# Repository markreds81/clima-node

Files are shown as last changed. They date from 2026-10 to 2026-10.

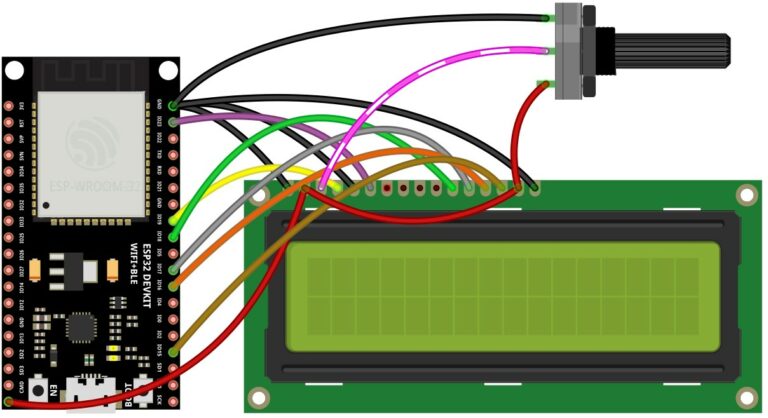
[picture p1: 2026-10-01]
docs/images/lcd-esp32-wiring.jpg

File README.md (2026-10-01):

# ClimaNode

Nodo climatico basato su ESP32-WROOM-32: legge temperatura e umidità da un sensore DHT22, le mostra su un display LCD 16x2 ed espone gli ultimi valori rilevati tramite una semplice API HTTP in JSON e una dashboard web.

## Hardware

- Scheda ESP32-WROOM-32
- Sensore DHT22
- Display LCD 16x2 (interfaccia parallela, driver HD44780 compatibile con `LiquidCrystal`)
- Encoder rotativo con pulsante integrato (es. KY-040)

### Collegamenti

| Componente | Pin ESP32 |
|---|---|
| DHT22 (data) | GPIO 21 |
| LCD RS | GPIO 19 |
| LCD E | GPIO 23 |
| LCD D4 | GPIO 18 |
| LCD D5 | GPIO 17 |
| LCD D6 | GPIO 16 |
| LCD D7 | GPIO 15 |
| Encoder CLK | GPIO 4 |
| Encoder DT | GPIO 22 |
| Encoder SW (push) | GPIO 27 |

## Librerie richieste

Da installare tramite Library Manager dell'Arduino IDE:

- **DHT sensor library** (Adafruit) — con la sua dipendenza **Adafruit Unified Sensor**
- **LiquidCrystal** (libreria standard, inclusa con l'Arduino IDE)
- **RotaryEncoder** (Matthias Hertel)
- **ESP Async WebServer** (ESP32Async) — con la sua dipendenza **Async TCP** (ESP32Async)

Incluse direttamente nel progetto (nessuna installazione necessaria):

- `Button` ([mrButton](https://github.com/markreds81/Button) di Mark Reds, vendorizzata come `Button.h`/`Button.cpp`)

Già incluse nel core ESP32 (nessuna installazione necessaria, basta avere il core ESP32 installato tramite Boards Manager):

- `WiFi`
- `ESPmDNS`

## Setup credenziali WiFi

Le credenziali WiFi non sono versionate nel repository. Prima di compilare:

1. Copia il file di esempio:
   ```sh
   cp Secrets.h.example Secrets.h
   ```
2. Modifica `Secrets.h` inserendo SSID e password delle reti WiFi disponibili (sono supportate fino a due reti, il nodo si connette a quella con il segnale migliore e, se la connessione cade, riprova automaticamente senza bloccare display e sensore):
   ```cpp
   #define WIFI_SSID_1  "NomeRete1"
   #define WIFI_PASS_1  "Password1"

   #define WIFI_SSID_2  "NomeRete2"
   #define WIFI_PASS_2  "Password2"
   ```

`Secrets.h` è ignorato da git (vedi `.gitignore`) e non verrà mai inviato al repository remoto.

## Upload

Apri `ClimaNode.ino` con l'Arduino IDE, seleziona la board ESP32-WROOM-32 e la porta seriale corretta, quindi carica lo sketch.

Al boot il device si connette al WiFi (log disponibile su Serial a 9600 baud) e, una volta connesso, avvia anche il responder mDNS, raggiungibile come `climanode-XXXXXX.local` sulla rete locale.

## Identificazione del nodo

Ogni nodo è identificato dal MAC address di fabbrica dell'ESP32 (scritto nell'eFuse, unico per chip e indipendente dal firmware):

- **ID**: il MAC in esadecimale minuscolo, es. `a1b2c3d4e5f6`. È incluso in tutte le risposte dell'API (campo `id`) e nel record TXT `id` del servizio mDNS `_http._tcp`.
- **Hostname**: `climanode-` seguito dagli ultimi 3 byte del MAC, es. `climanode-d4e5f6`. È usato sia per mDNS (`climanode-d4e5f6.local`) sia come nome DHCP, così più nodi possono convivere sulla stessa rete.

ID e hostname sono stampati su Serial all'avvio. Per elencare i nodi presenti sulla rete da macOS:

```sh
dns-sd -B _http._tcp
```

## Display LCD

Il display mostra sei schermate, che si scorrono ruotando l'encoder in entrambe le direzioni:

- **Clima**: temperatura e umidità rilevate dal DHT22, indicate da due icone (termometro e goccia). In fondo a ogni riga una freccia indica la tendenza: ↑ in salita, ↓ in discesa, → stabile, calcolata confrontando la media dell'ultimo minuto con quella di 10 minuti prima (soglie: 0,3 °C e 2% di umidità). Nei primi minuti dopo l'avvio, finché lo storico non è sufficiente, la freccia non viene mostrata.
- **Rete**: indirizzo IP e stato della connessione WiFi.
- **Segnale**: qualità del segnale WiFi (ottimo, buono, discreto, scarso), una barra proporzionale e il valore RSSI in dBm, aggiornati ogni secondo.
- **Data e ora**: data e ora correnti, sincronizzate via NTP (fuso Europe/Rome con ora legale automatica).
- **Nodo**: ID del nodo (MAC di fabbrica) e hostname.
- **Firmware**: versione del firmware installato.

Il pulsante integrato nell'encoder è collegato (GPIO 27) ma al momento non ha alcuna funzione.

## Dashboard web

Una volta connesso alla rete, aprendo `http://climanode-XXXXXX.local/` (o l'IP stampato su Serial) nel browser è disponibile una dashboard single-page che mostra ID del nodo, versione del firmware, data e ora del device, temperatura e umidità con la relativa tendenza, e stato della connessione WiFi (SSID, potenza del segnale, IP, canale), aggiornata automaticamente ogni 3 secondi.

## API

Il device espone anche due endpoint HTTP in JSON, usati dalla dashboard ma interrogabili anche direttamente:

```
GET /api/v1/climate
```

```json
{"id":"a1b2c3d4e5f6","temperature":21.5,"humidity":48.2,"trend":{"temperature":"up","humidity":"steady"}}
```

`trend` indica la tendenza di ciascun valore negli ultimi 10 minuti (come le frecce sul display): `up`, `down`, `steady`, oppure `unknown` nei primi minuti dopo l'avvio.

```
GET /api/v1/status
```

```json
{"id":"a1b2c3d4e5f6","firmware":"1.0a","wifi":{"connected":true,"ssid":"NomeRete","rssi":-58,"ip":"192.168.1.50","channel":6},"time":{"synced":true,"local":"2026-10-01T14:05:32"}}
```

Se il device non è connesso al WiFi, `wifi.connected` risulta `false` e gli altri campi sono assenti. `time.local` è l'ora locale del device in formato ISO 8601 senza offset; finché l'ora non è sincronizzata via NTP `time.synced` risulta `false` e `local` è assente.

Esempio con `curl`, usando l'IP stampato su Serial oppure l'hostname mDNS:

```sh
curl http://climanode-d4e5f6.local/api/v1/climate
curl http://climanode-d4e5f6.local/api/v1/status
```

## Licenza

Distribuito sotto licenza [MIT](LICENSE).

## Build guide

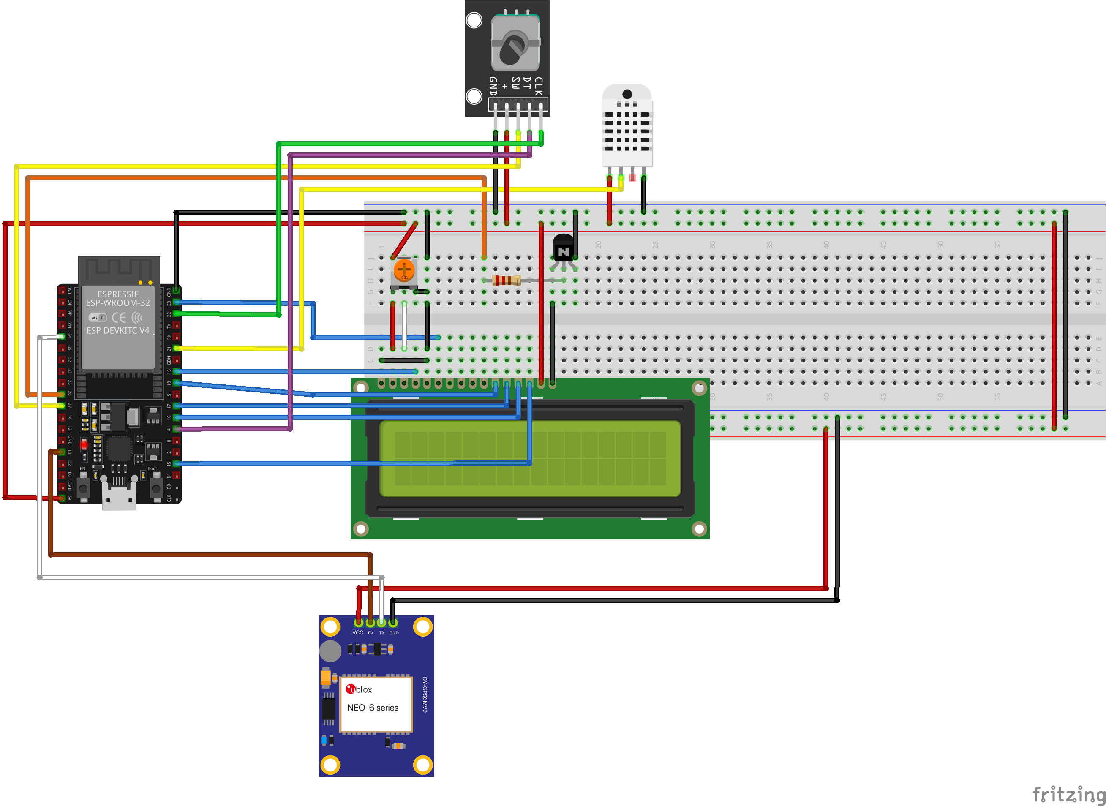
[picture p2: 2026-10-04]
docs/images/climanode-wiring.png

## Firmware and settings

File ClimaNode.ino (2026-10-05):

#include <DHT.h>
#include <LiquidCrystal.h>
#include <WiFi.h>
#include <ESPAsyncWebServer.h>
#include <ESPmDNS.h>
#include <esp_mac.h>
#include <RotaryEncoder.h>
#include <TinyGPSPlus.h>
#include <sys/time.h>
#include "time.h"
#include "Timer.h"
#include "Secrets.h"
#include "Dashboard.h"
#include "Button.h"
#include "Trend.h"
#include "Glyphs.h"

#define LCD_RS            19
#define LCD_EN            23
#define LCD_D4            18
#define LCD_D5            17
#define LCD_D6            16
#define LCD_D7            15
#define LCD_BACKLIGHT     26
#define DHT_PIN           21
#define DHT_TYPE          DHT22
#define HTTP_PORT         80
#define HOSTNAME_PREFIX   "climanode"
#define FIRMWARE_VERSION  "1.0a"
#define ROTARY_CLK        4
#define ROTARY_DT         22
#define ROTARY_SW         27
#define BACKLIGHT_TIMEOUT 30000L
#define GPS_RX            34
#define GPS_TX            13
#define GPS_BAUD          9600
#define GPS_MAX_AGE       3000

#define NTP_SERVER        "ntp1.inrim.it"
// Europe/Rome: CET (UTC+1), CEST (UTC+2) dall'ultima domenica di marzo all'ultima di ottobre
#define TIME_ZONE         "CET-1CEST,M3.5.0,M10.5.0/3"

DHT dht(DHT_PIN, DHT_TYPE);
LiquidCrystal lcd(LCD_RS, LCD_EN, LCD_D4, LCD_D5, LCD_D6, LCD_D7);
RotaryEncoder rot(ROTARY_CLK, ROTARY_DT, RotaryEncoder::LatchMode::FOUR3);
Button btn(ROTARY_SW);
AsyncWebServer httpServer(HTTP_PORT);
Timer linkTimer;
Timer pollTimer;
Timer clockTimer;
Timer trendTimer;
Timer backlightTimer;
Timer gpsTimer;
TinyGPSPlus gps;
Trend temperatureTrend(0.3f);  // °C in TREND_WINDOW_MIN minuti
Trend humidityTrend(2.0f);     // % in TREND_WINDOW_MIN minuti
volatile TrendDirection temperatureDirection = TREND_UNKNOWN;
volatile TrendDirection humidityDirection = TREND_UNKNOWN;

enum DisplayScreen {
  SCREEN_CLIMATE,
  SCREEN_NETWORK,
  SCREEN_SIGNAL,
  SCREEN_TIME,
  SCREEN_GPS,
  SCREEN_NODE,
  SCREEN_FIRMWARE,
  SCREEN_COUNT
};

struct GpsInfo {
  bool fix;
  uint32_t satellites;
  double latitude;
  double longitude;
  double altitude;  // m s.l.m.
  double hdop;
};

GpsInfo gpsInfo = {};
portMUX_TYPE gpsMux = portMUX_INITIALIZER_UNLOCKED;

struct KnownNetwork {
  const char *ssid;
  const char *pass;
};

const KnownNetwork knownNetworks[] = {
  { WIFI_SSID_1, WIFI_PASS_1 },
  { WIFI_SSID_2, WIFI_PASS_2 }
};

enum LinkState {
  LINK_IDLE,        // in attesa del prossimo tentativo
  LINK_SCANNING,    // scansione asincrona in corso
  LINK_CONNECTING,  // WiFi.begin() avviato, in attesa dell'esito
  LINK_CONNECTED
};

const uint32_t connectTimeoutMs = 10000;
const uint32_t scanTimeoutMs = 15000;
const uint32_t retryDelayMs = 5000;
LinkState linkState = LINK_IDLE;
uint32_t linkStateSince = 0;
uint8_t wifiStatus = WL_NO_SHIELD;
bool mdnsStarted = false;
char nodeId[13];    // MAC di fabbrica (eFuse) in esadecimale, es. "a1b2c3d4e5f6"
char hostname[24];  // HOSTNAME_PREFIX + ultimi 3 byte del MAC, es. "climanode-d4e5f6"
float humidity = 0.0f;
float temperature = 0.0f;
DisplayScreen currentScreen = SCREEN_CLIMATE;
bool backlightOn = true;

uint8_t trendSymbol(TrendDirection trend) {
  switch (trend) {
    case TREND_UP:
      return ICON_TREND_UP;
    case TREND_DOWN:
      return ICON_TREND_DOWN;
    case TREND_STEADY:
      return LCD_RIGHT_ARROW;
    default:
      return ' ';
  }
}

void printClimateLine(uint8_t row, uint8_t icon, const char *value, TrendDirection trend) {
  lcd.setCursor(0, row);
  lcd.print(' ');
  lcd.write(icon);
  lcd.printf(" %-11s", value);
  lcd.write(trendSymbol(trend));
  lcd.print(' ');
}

void renderClimateScreen() {
  char value[14];

  snprintf(value, sizeof(value), "%5.1f%cC", temperature, LCD_DEGREE);
  printClimateLine(0, ICON_THERMOMETER, value, temperatureTrend.direction());

  snprintf(value, sizeof(value), "%5.1f%%", humidity);
  printClimateLine(1, ICON_DROP, value, humidityTrend.direction());
}

void renderNetworkScreen() {
  lcd.setCursor(0, 0);
  if (WiFi.status() == WL_CONNECTED) {
    lcd.print(WiFi.localIP().toString());
    lcd.print("                ");
  } else {
    lcd.print("IP non disp.    ");
  }

  lcd.setCursor(0, 1);
  lcd.print(WiFi.status() == WL_CONNECTED ? "WiFi: Connesso  " : "WiFi: Assente   ");
}

const char *signalQuality(int rssi) {
  if (rssi >= -55) return "ottimo";
  if (rssi >= -65) return "buono";
  if (rssi >= -75) return "discreto";
  return "scarso";
}

void renderSignalScreen() {
  char line[17];

  if (WiFi.status() != WL_CONNECTED) {
    lcd.setCursor(0, 0);
    lcd.print("Segnale WiFi    ");
    lcd.setCursor(0, 1);
    lcd.print("Non connesso    ");
    return;
  }

  int rssi = WiFi.RSSI();
  snprintf(line, sizeof(line), "Segnale %-8s", signalQuality(rssi));
  lcd.setCursor(0, 0);
  lcd.print(line);

  // Barra di 9 celle da -90 dBm (vuota) a -30 dBm (piena), poi il valore in dBm
  const int barCells = 9;
  int filled = constrain(map(rssi, -90, -30, 0, barCells), 0, barCells);
  for (int i = 0; i < barCells; i++) {
    line[i] = i < filled ? LCD_FULL_BLOCK : LCD_MIDDLE_DOT;
  }
  snprintf(line + barCells, sizeof(line) - barCells, "%4ddBm", rssi);
  lcd.setCursor(0, 1);
  lcd.print(line);
}

void renderTimeScreen() {
  struct tm timeInfo;
  
  if (!getLocalTime(&timeInfo, 0)) {
    lcd.setCursor(0, 0);
    lcd.print("Ora non sincr.  ");
    lcd.setCursor(0, 1);
    lcd.print("Attesa NTP...   ");
    return;
  }

  char line[17];
  strftime(line, sizeof(line), "   %d/%m/%Y   ", &timeInfo);
  lcd.setCursor(0, 0);
  lcd.print(line);

  strftime(line, sizeof(line), "    %H:%M:%S    ", &timeInfo);
  lcd.setCursor(0, 1);
  lcd.print(line);
}

GpsInfo readGpsInfo() {
  taskENTER_CRITICAL(&gpsMux);
  GpsInfo info = gpsInfo;
  taskEXIT_CRITICAL(&gpsMux);
  return info;
}

void renderGpsScreen() {
  GpsInfo info = readGpsInfo();
  char line[17];

  if (!info.fix) {
    lcd.setCursor(0, 0);
    lcd.print("GPS: ricerca... ");
    snprintf(line, sizeof(line), "Satelliti: %-5lu", (unsigned long)info.satellites);
    lcd.setCursor(0, 1);
    lcd.print(line);
    return;
  }

  snprintf(line, sizeof(line), "Lat: %9.5f %c", fabs(info.latitude), info.latitude < 0 ? 'S' : 'N');
  lcd.setCursor(0, 0);
  lcd.print(line);

  snprintf(line, sizeof(line), "Lon: %9.5f %c", fabs(info.longitude), info.longitude < 0 ? 'W' : 'E');
  lcd.setCursor(0, 1);
  lcd.print(line);
}

void renderNodeScreen() {
  char line[17];
  snprintf(line, sizeof(line), "ID: %-12.12s", nodeId);
  lcd.setCursor(0, 0);
  lcd.print(line);

  snprintf(line, sizeof(line), "%-16.16s", hostname);
  lcd.setCursor(0, 1);
  lcd.print(line);
}

void renderFirmwareScreen() {
  char line[17];
  lcd.setCursor(0, 0);
  lcd.print("ClimaNode       ");

  snprintf(line, sizeof(line), "Firmware %-7s", FIRMWARE_VERSION);
  lcd.setCursor(0, 1);
  lcd.print(line);
}

void wakeBacklight() {
  backlightTimer.reset();
  if (!backlightOn) {
    backlightOn = true;
    digitalWrite(LCD_BACKLIGHT, HIGH);
  }
}

void renderDisplay() {
  switch (currentScreen) {
    case SCREEN_CLIMATE:
      renderClimateScreen();
      break;
    case SCREEN_NETWORK:
      renderNetworkScreen();
      break;
    case SCREEN_SIGNAL:
      renderSignalScreen();
      break;
    case SCREEN_TIME:
      renderTimeScreen();
      break;
    case SCREEN_GPS:
      renderGpsScreen();
      break;
    case SCREEN_NODE:
      renderNodeScreen();
      break;
    case SCREEN_FIRMWARE:
      renderFirmwareScreen();
      break;
  }
}

void readEnvironment() {
  float newHumidity = dht.readHumidity();
  float newTemperature = dht.readTemperature();

  if (isnan(newHumidity) || isnan(newTemperature)) {
    Serial.println("Errore: lettura sensore non valida");
    if (currentScreen == SCREEN_CLIMATE) {
      lcd.setCursor(0, 0);
      lcd.print("Errore sensore  ");
      lcd.setCursor(0, 1);
      lcd.print("Dati non validi ");
    }
    return;
  }

  humidity = newHumidity;
  temperature = newTemperature;
  humidityTrend.add(humidity);
  temperatureTrend.add(temperature);

#ifdef DHT_DEBUG
  Serial.print("Umidità: ");
  Serial.print(humidity, 1);
  Serial.print("%, Temperatura: ");
  Serial.print(temperature, 1);
  Serial.println("° Celsius");
#endif

  if (currentScreen == SCREEN_CLIMATE) {
    renderClimateScreen();
  }
}

// Copia src in dst come contenuto di una stringa JSON (senza virgolette esterne)
void jsonEscape(const char *src, char *dst, size_t size) {
  size_t n = 0;
  for (; *src && n + 7 <= size; src++) {
    unsigned char c = *src;
    if (c == '"' || c == '\\') {
      dst[n++] = '\\';
      dst[n++] = c;
    } else if (c < 0x20) {
      n += snprintf(dst + n, size - n, "\\u%04x", c);
    } else {
      dst[n++] = c;
    }
  }
  dst[n] = '\0';
}

const char *trendName(TrendDirection trend) {
  switch (trend) {
    case TREND_UP:
      return "up";
    case TREND_DOWN:
      return "down";
    case TREND_STEADY:
      return "steady";
    default:
      return "unknown";
  }
}

void handleClimateRequest(AsyncWebServerRequest *request) {
  char location[96];
  char payload[256];

  // Posizione della misura; null finché il GPS non ha il fix
  GpsInfo info = readGpsInfo();
  if (info.fix) {
    snprintf(location, sizeof(location), "{\"latitude\":%.6f,\"longitude\":%.6f,\"altitude\":%.1f}",
             info.latitude, info.longitude, info.altitude);
  } else {
    snprintf(location, sizeof(location), "null");
  }

  snprintf(payload, sizeof(payload),
           "{\"id\":\"%s\",\"temperature\":%.1f,\"humidity\":%.1f,"
           "\"trend\":{\"temperature\":\"%s\",\"humidity\":\"%s\"},\"location\":%s}",
           nodeId, temperature, humidity,
           trendName(temperatureDirection), trendName(humidityDirection), location);
  request->send(200, "application/json", payload);
}

void handleStatusRequest(AsyncWebServerRequest *request) {
  char wifi[320];
  char clock[64];
  char receiver[64];
  char payload[640];

  if (WiFi.status() == WL_CONNECTED) {
    char ssid[32 * 6 + 1];  // SSID max 32 byte, ognuno al più \u00XX
    jsonEscape(WiFi.SSID().c_str(), ssid, sizeof(ssid));
    snprintf(wifi, sizeof(wifi),
             "{\"connected\":true,\"ssid\":\"%s\",\"rssi\":%d,\"ip\":\"%s\",\"channel\":%d}",
             ssid, WiFi.RSSI(), WiFi.localIP().toString().c_str(), WiFi.channel());
  } else {
    snprintf(wifi, sizeof(wifi), "{\"connected\":false}");
  }

  // Ora locale del device (fuso TIME_ZONE) in formato ISO 8601 senza offset
  struct tm timeInfo;
  if (getLocalTime(&timeInfo, 0)) {
    char local[20];
    strftime(local, sizeof(local), "%Y-%m-%dT%H:%M:%S", &timeInfo);
    snprintf(clock, sizeof(clock), "{\"synced\":true,\"local\":\"%s\"}", local);
  } else {
    snprintf(clock, sizeof(clock), "{\"synced\":false}");
  }

  GpsInfo info = readGpsInfo();
  if (info.fix) {
    snprintf(receiver, sizeof(receiver), "{\"fix\":true,\"satellites\":%lu,\"hdop\":%.1f}",
             (unsigned long)info.satellites, info.hdop);
  } else {
    snprintf(receiver, sizeof(receiver), "{\"fix\":false,\"satellites\":%lu}",
             (unsigned long)info.satellites);
  }

  snprintf(payload, sizeof(payload),
           "{\"id\":\"%s\",\"firmware\":\"%s\",\"wifi\":%s,\"time\":%s,\"gps\":%s}",
           nodeId, FIRMWARE_VERSION, wifi, clock, receiver);
  request->send(200, "application/json", payload);
}

void handleDashboardRequest(AsyncWebServerRequest *request) {
  request->send(200, "text/html", (const uint8_t *)DASHBOARD_HTML, sizeof(DASHBOARD_HTML) - 1);
}

void startMdns() {
  if (mdnsStarted) {
    return;
  }

  if (MDNS.begin(hostname)) {
    MDNS.addService("http", "tcp", HTTP_PORT);
    MDNS.addServiceTxt("http", "tcp", "id", (const char *)nodeId);
    mdnsStarted = true;
    Serial.printf("[MDNS] Responder started: http://%s.local/\n", hostname);
  } else {
    Serial.println("[MDNS] Error starting responder.");
  }
}

void setLinkState(LinkState state) {
  linkState = state;
  linkStateSince = millis();
}

void startWifiScan() {
  WiFi.disconnect();
  WiFi.scanNetworks(true);
  setLinkState(LINK_SCANNING);
}

void connectBestNetwork(int found) {
  int bestIndex = -1;
  const KnownNetwork *bestNetwork = nullptr;

  for (int i = 0; i < found; i++) {
    for (const KnownNetwork &network : knownNetworks) {
      if (WiFi.SSID(i) == network.ssid && (bestIndex < 0 || WiFi.RSSI(i) > WiFi.RSSI(bestIndex))) {
        bestIndex = i;
        bestNetwork = &network;
      }
    }
  }

  if (bestNetwork == nullptr) {
    Serial.println("[WIFI] Connecting Failed AP not found.");
    setLinkState(LINK_IDLE);
  } else {
    Serial.printf("[WIFI] Connecting to %s (%d dBm)...\n", bestNetwork->ssid, WiFi.RSSI(bestIndex));
    WiFi.begin(bestNetwork->ssid, bestNetwork->pass, WiFi.channel(bestIndex), WiFi.BSSID(bestIndex));
    setLinkState(LINK_CONNECTING);
  }
  WiFi.scanDelete();
}

void updateWifiLink() {
  uint32_t elapsed = millis() - linkStateSince;

  switch (linkState) {
    case LINK_IDLE:
      if (elapsed >= retryDelayMs) {
        startWifiScan();
      }
      break;
    case LINK_SCANNING: {
      int found = WiFi.scanComplete();
      if (found >= 0) {
        connectBestNetwork(found);
      } else if (found == WIFI_SCAN_FAILED || elapsed >= scanTimeoutMs) {
        Serial.println("[WIFI] Scan failed.");
        WiFi.scanDelete();
        setLinkState(LINK_IDLE);
      }
      break;
    }
    case LINK_CONNECTING:
      if (WiFi.status() == WL_CONNECTED) {
        setLinkState(LINK_CONNECTED);
      } else if (elapsed >= connectTimeoutMs) {
        Serial.println("[WIFI] Connecting Failed (timeout).");
        WiFi.disconnect();
        setLinkState(LINK_IDLE);
      }
      break;
    case LINK_CONNECTED:
      if (WiFi.status() != WL_CONNECTED) {
        startWifiScan();
      }
      break;
  }
}

// Secondi dal 1/1/1970 di una data UTC (algoritmo days_from_civil di H. Hinnant)
time_t utcToEpoch(int year, int month, int day, int hour, int minute, int second) {
  year -= month <= 2;
  int era = year / 400;
  int yoe = year - era * 400;
  int doy = (153 * (month + (month > 2 ? -3 : 9)) + 2) / 5 + day - 1;
  int doe = yoe * 365 + yoe / 4 - yoe / 100 + doy;
  long days = era * 146097L + doe - 719468;
  return (time_t)days * 86400 + hour * 3600 + minute * 60 + second;
}

// Se l'orologio non è ancora stato impostato (es. NTP non raggiungibile) usa l'ora del GPS
void syncClockFromGps() {
  struct tm timeInfo;

  if (getLocalTime(&timeInfo, 0)) {
    return;
  }
  
  if (!gps.location.isValid() || gps.time.age() > GPS_MAX_AGE || gps.date.year() < 2024) {
    return;
  }

  struct timeval now = {
    .tv_sec = utcToEpoch(gps.date.year(), gps.date.month(), gps.date.day(),
                         gps.time.hour(), gps.time.minute(), gps.time.second()),
    .tv_usec = 0
  };
  settimeofday(&now, nullptr);
  Serial.println("[GPS] Clock set from GPS.");
}

void updateGpsInfo() {
  GpsInfo info = {};
  info.fix = gps.location.isValid() && gps.location.age() < GPS_MAX_AGE;
  info.satellites = gps.satellites.isValid() ? gps.satellites.value() : 0;
  if (info.fix) {
    info.latitude = gps.location.lat();
    info.longitude = gps.location.lng();
    info.altitude = gps.altitude.meters();
    info.hdop = gps.hdop.hdop();
  }

  taskENTER_CRITICAL(&gpsMux);
  gpsInfo = info;
  taskEXIT_CRITICAL(&gpsMux);

#ifdef GPS_DEBUG
  Serial.printf("[GPS] fix: %d, sat: %lu, lat: %.6f, lon: %.6f, chars: %lu, bad checksum: %lu\n",
                info.fix, (unsigned long)info.satellites, info.latitude, info.longitude,
                (unsigned long)gps.charsProcessed(), (unsigned long)gps.failedChecksum());
#endif
}

// Ricava ID e hostname dal MAC di fabbrica, unico per ogni chip
void initNodeIdentity() {
  uint8_t mac[6];
  esp_efuse_mac_get_default(mac);
  snprintf(nodeId, sizeof(nodeId), "%02x%02x%02x%02x%02x%02x",
           mac[0], mac[1], mac[2], mac[3], mac[4], mac[5]);
  snprintf(hostname, sizeof(hostname), HOSTNAME_PREFIX "-%02x%02x%02x", mac[3], mac[4], mac[5]);
}

void setup() {
  Serial.begin(9600);
  Serial1.setRxBufferSize(1024);
  Serial1.begin(GPS_BAUD, SERIAL_8N1, GPS_RX, GPS_TX);

  pinMode(LCD_BACKLIGHT, OUTPUT);
  digitalWrite(LCD_BACKLIGHT, HIGH);
  
  dht.begin();
  btn.begin();
  
  lcd.begin(16, 2);
  lcd.createChar(ICON_THERMOMETER, thermometerGlyph);
  lcd.createChar(ICON_DROP, dropGlyph);
  lcd.createChar(ICON_TREND_UP, trendUpGlyph);
  lcd.createChar(ICON_TREND_DOWN, trendDownGlyph);
  
  initNodeIdentity();
  Serial.printf("[NODE] ID: %s, hostname: %s, firmware: %s\n", nodeId, hostname, FIRMWARE_VERSION);
  
  WiFi.setHostname(hostname);
  WiFi.mode(WIFI_STA);
  WiFi.setSleep(false);
  WiFi.enableIPv6();
  WiFi.setAutoReconnect(false);  // La riconnessione è gestita da updateWifiLink()
  
  setenv("TZ", TIME_ZONE, 1);    // Fuso orario impostato subito, così vale anche per l'ora presa dal GPS prima dell'NTP
  tzset();
  startWifiScan();
  
  linkTimer.begin(1000L);
  pollTimer.begin(2000L);
  clockTimer.begin(250L);
  trendTimer.begin(60000L);
  backlightTimer.begin(BACKLIGHT_TIMEOUT);
  gpsTimer.begin(1000L);

  httpServer.on("/", HTTP_GET, handleDashboardRequest);
  httpServer.on("/api/v1/climate", HTTP_GET, handleClimateRequest);
  httpServer.on("/api/v1/status", HTTP_GET, handleStatusRequest);
  httpServer.begin();
}

void loop() {
  static int pos = 0;

  if (backlightOn && backlightTimer.expired()) {
    backlightOn = false;
    digitalWrite(LCD_BACKLIGHT, LOW);
  }

  if (linkTimer.expired()) {
    updateWifiLink();
    uint8_t status = WiFi.status();
    if (status != wifiStatus) {
			wifiStatus = status;
			switch (status) {
				case WL_CONNECTED:
					Serial.println("[WIFI] Connecting done.");
					Serial.printf("[WIFI] IP: %s\n", WiFi.localIP().toString().c_str());
					Serial.printf("[WIFI] MAC: %s\n", WiFi.macAddress().c_str());
					Serial.printf("[WIFI] SSID: %s\n", WiFi.SSID().c_str());
					Serial.printf("[WIFI] BSSID: %s\n", WiFi.BSSIDstr().c_str());
					Serial.printf("[WIFI] Channel: %d\n", WiFi.channel());
					configTzTime(TIME_ZONE, NTP_SERVER);
					startMdns();
					break;
				case WL_NO_SSID_AVAIL:
					Serial.println("[WIFI] Connecting Failed AP not found.");
					break;
				case WL_CONNECT_FAILED:
					Serial.println("[WIFI] Connecting Failed.");
					break;
				case WL_DISCONNECTED:
					Serial.println("[WIFI] Disconnected.");
					break;
				default:
					Serial.printf("[WIFI] Connecting Failed (%d).\n", status);
			}
			if (currentScreen == SCREEN_NETWORK) {
				renderNetworkScreen();
			}
		}
    if (currentScreen == SCREEN_SIGNAL) {
      renderSignalScreen();
    }
    linkTimer.reset();
  }

  if (pollTimer.expired()) {
    pollTimer.reset();
    readEnvironment();
  }

  if (trendTimer.expired()) {
    trendTimer.reset();
    temperatureTrend.commit();
    humidityTrend.commit();
    temperatureDirection = temperatureTrend.direction();
    humidityDirection = humidityTrend.direction();
    if (currentScreen == SCREEN_CLIMATE) {
      renderClimateScreen();
    }
  }

  if (clockTimer.expired()) {
    clockTimer.reset();
    if (currentScreen == SCREEN_TIME) {
      renderTimeScreen();
    }
  }

  rot.tick();
  int newPos = rot.getPosition();
  if (pos != newPos) {
    // Con il display spento la rotazione serve solo a riaccenderlo
    bool wasOn = backlightOn;
    wakeBacklight();
    if (wasOn) {
      int step = (newPos > pos) ? 1 : SCREEN_COUNT - 1;
      currentScreen = (DisplayScreen)((currentScreen + step) % SCREEN_COUNT);
      lcd.clear();
      renderDisplay();
    }
    pos = newPos;

#ifdef ROT_DEBUG
    Serial.print("pos:");
    Serial.print(newPos);
    Serial.print(" dir:");
    Serial.println((int)(rot.getDirection()));
#endif
  }

  if (btn.pressed()) {
    wakeBacklight();
    Serial.println("Button PRESSED");
  }

  while (Serial1.available() > 0) {
    gps.encode(Serial1.read());
  }

  if (gpsTimer.expired()) {
    gpsTimer.reset();
    updateGpsInfo();
    syncClockFromGps();
    if (currentScreen == SCREEN_GPS) {
      renderGpsScreen();
    }
  }
}

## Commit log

2026-09-30 Initial commit: DHT + LCD climate node with WiFi credentials externalized
    Move WiFi SSID/password out of source into a gitignored Secrets.h,
    add Secrets.h.example as a template, and fix a missing break in the
    WiFi status switch that caused duplicate "Connecting Failed" logs.
    [ClimaNode.ino]
2026-09-30 Add HTTP API endpoint for current climate readings
    Use the ESP32 core's built-in WebServer library (no extra dependency
    needed) to expose GET /api/climate, returning the latest temperature
    and humidity as JSON.
2026-09-30 Add mDNS responder so the device is reachable as climanode.local
    Uses the ESP32 core's built-in ESPmDNS library (no extra dependency).
    Responder starts once, on first successful WiFi connection, and
    advertises the HTTP service on port 80.
2026-09-30 Add README with hardware wiring, library and setup instructions
2026-09-30 Add rotary encoder screen switching and vendor Button library
    The LCD now toggles between a climate screen (temperature/humidity)
    and a network screen (IP and WiFi status) on each rotary encoder
    step. The encoder's push button is wired but not yet wired to any
    action. Vendors the mrButton library (Button.h/Button.cpp) directly
    in the project since it isn't published on the Arduino Library
    Manager. Also gates the verbose DHT serial logging behind a
    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
2026-10-01 Added LCD-ESP32 wiring scheme
2026-10-01 Add NTP clock, async web server and non-blocking WiFi reconnection
    Syncs the time via NTP (Europe/Rome time zone with automatic DST) and
    adds a third LCD screen with the current date and time; the rotary
    encoder now cycles through all screens in both directions. The status
    API exposes the device's local time and the dashboard shows it in a
    clock card aligned to the second.
    Replaces WebServer with ESPAsyncWebServer so idle browser connections
    no longer stall other requests, and serves the dashboard from flash.
    Enables IPv6 so mDNS answers AAAA queries (avoids a 5 s lookup delay
    for climanode.local), disables WiFi modem sleep to cut latency, and
    escapes the SSID in the status JSON.
    Replaces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
    [ClimaNode.ino]
2026-10-01 Identify nodes by factory MAC and use a unique hostname
    Derives a node ID from the ESP32 eFuse MAC and a hostname of the form
    climanode-XXXXXX (last 3 MAC bytes), used for both mDNS and DHCP so
    multiple nodes can share a network. The ID is included in every API
    response, published as the "id" TXT record of the mDNS HTTP service,
    shown in the dashboard subtitle and on a new LCD screen together with
    the hostname. Also brings the README up to date with the display
    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
2026-10-01 Add climate trends, WiFi signal and firmware screens
    Replaces the "Tmp:"/"Hum:" labels on the climate screen with custom
    thermometer and drop icons, and adds a trend arrow to each value: the
    Trend class compares the last minute's average with the one 10 minutes
    earlier (thresholds 0.3 °C and 2%). Trends are exposed in the climate
    API and shown next to the values in the dashboard.
    Adds an LCD screen with the WiFi signal quality, a bar and the RSSI,
    and one with the firmware version (1.0a), which is also exposed in the
    status API and shown in the dashboard subtitle. Moves the Trend class
    to Trend.h/Trend.cpp and the LCD glyphs to Glyphs.h.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
    [ClimaNode.ino]
2026-10-02 Turn off LCD backlight after inactivity
    Drives the LCD backlight from GPIO 26 and switches it off after 30 s
    (BACKLIGHT_TIMEOUT) without input. Turning the encoder or pressing its
    button switches it back on; the rotation that wakes the display does
    not change the screen. Encoder position logging is now only compiled
    with ROT_DEBUG.
2026-10-04 Add GPS receiver with position in climate API and dashboard
    Parse NMEA from the GPS module with TinyGPSPlus on Serial1 (RX on
    GPIO34, not a strapping pin). Add an LCD screen with fix status and
    coordinates, set the clock from GPS when NTP is not available, report
    the measurement position in /api/v1/climate and the receiver status in
    /api/v1/status, and show both on the dashboard.
    [ClimaNode.ino]
2026-10-04 Add wiring diagram
    Fritzing source and exported image of the breadboard wiring, including
    the GPS module (TX on GPIO34, RX on GPIO13).
    [climanode-wiring.fzz]
